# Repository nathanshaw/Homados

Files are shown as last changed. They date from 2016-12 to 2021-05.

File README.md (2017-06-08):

Machine Orchesta
# Homados

16 Channel Solenoid Driver

Please note that for each board you much change the ARDUINO_ID to a unique number

If you want to turn off LED feedback change LED_FEEDBACK to 0

If you don't want the startup sequence change BOOT_TEST to 0

If the LED is not yellow during the BOOT_TEST change your led pins until it is.

-------------------

Homados is the larger of the two actuator shields in the Pantheon system and is 
fashioned for use with the Arduino Mega microcontroller. The board supports 
sixteen channels of actuator control, three I2C jacks, and a RGB status LED. The 
first fifteen channels of the Homados driver utilizes PWM while the sixteenth channel 
uses a standard digital pin. The Homados is intended to function as a larger version of 
the Brigid shield and is to be used when six channels of control are inadequate. The 
Homados shield is functionally comparable to the Brigid in all ways.

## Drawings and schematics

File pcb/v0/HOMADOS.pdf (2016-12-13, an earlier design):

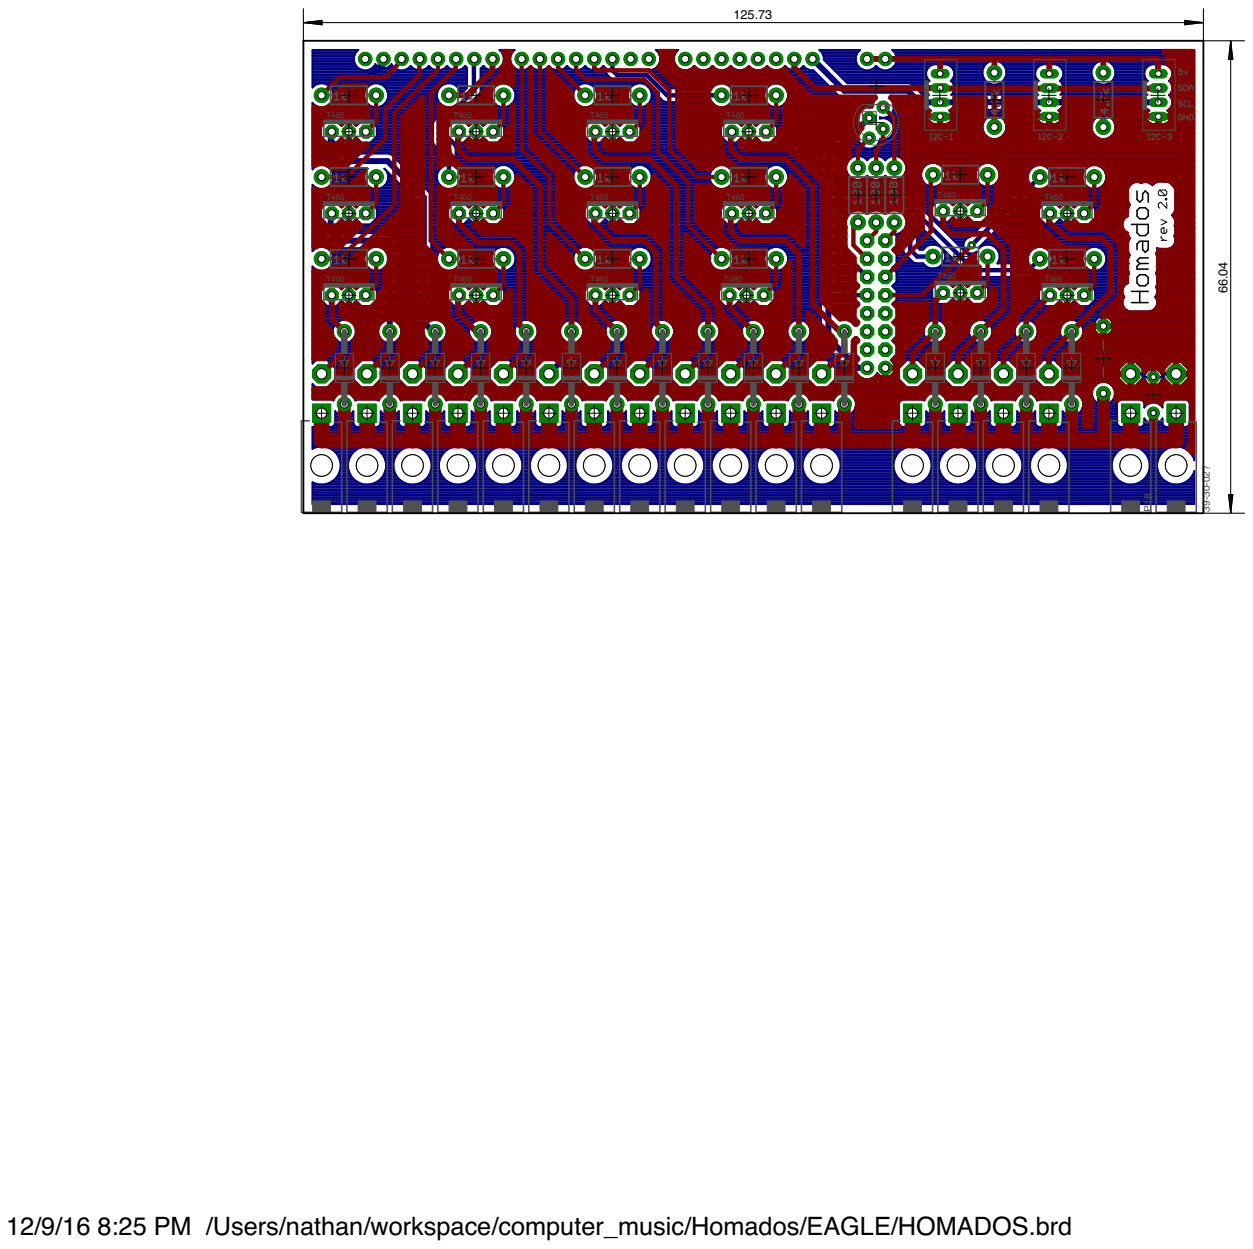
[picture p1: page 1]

12/9/16 8:25 PM /Users/nathan/workspace/computer_music/Homados/EAGLE/HOMADOS.brd

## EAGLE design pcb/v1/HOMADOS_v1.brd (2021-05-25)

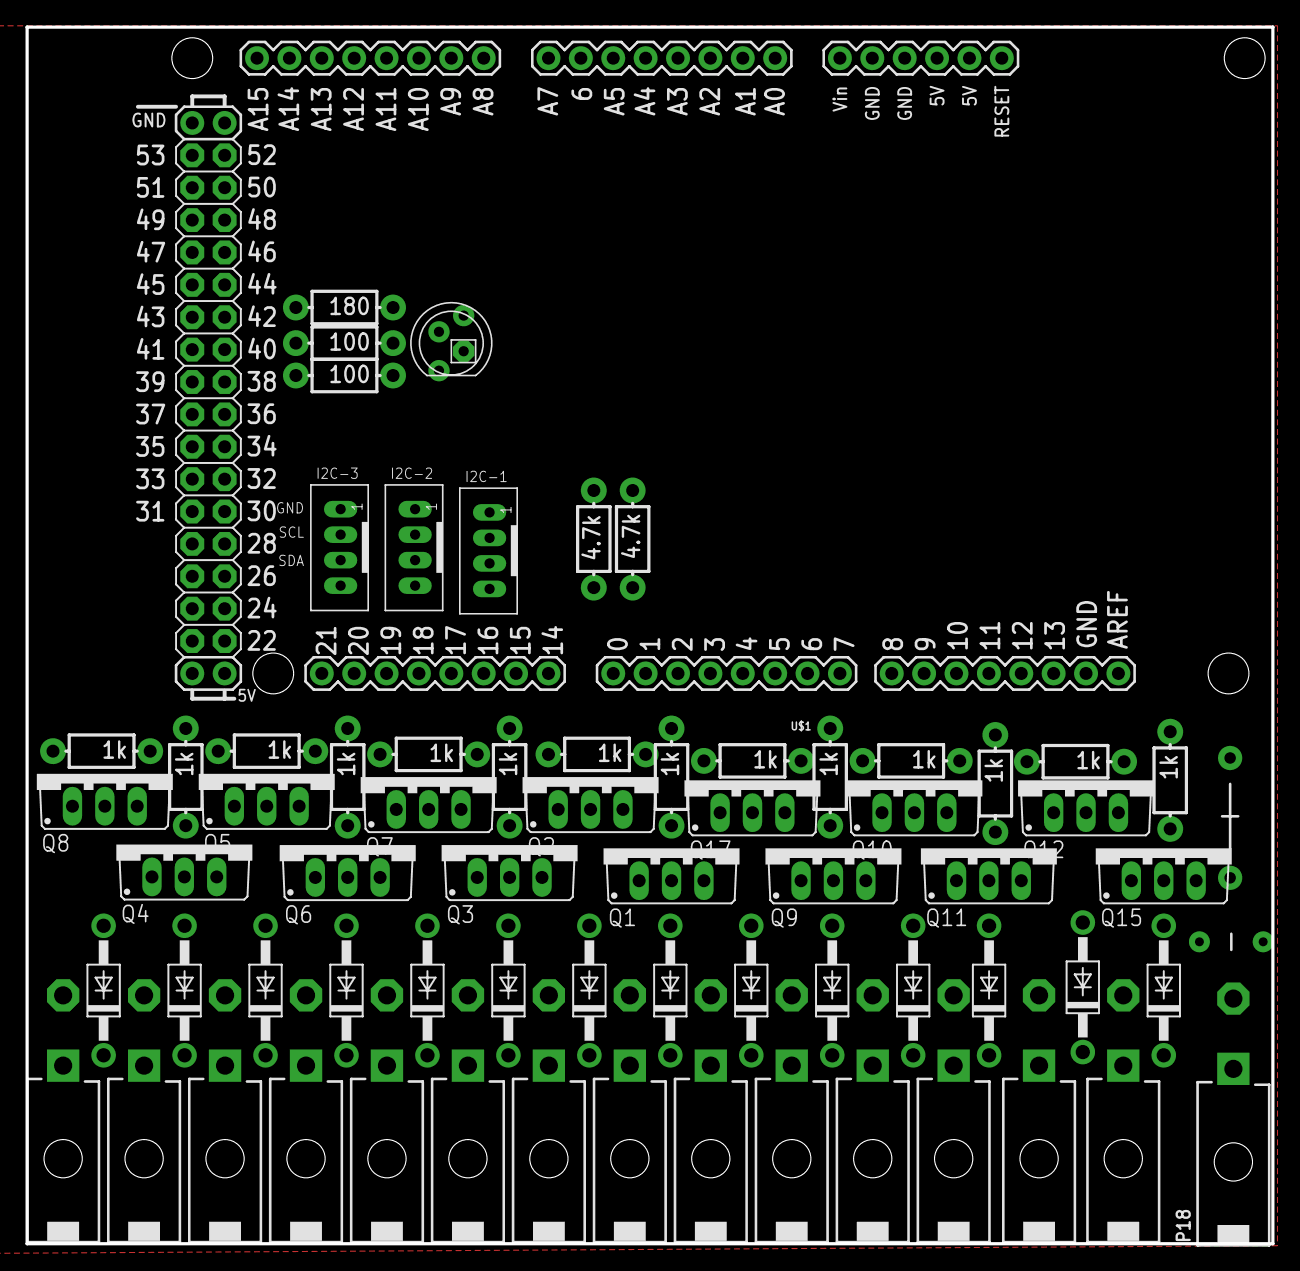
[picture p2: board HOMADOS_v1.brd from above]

Board: 2 copper layers, 97.7 x 95.4 mm, 69 parts (0 on the bottom side), 54 nets, no tracks yet.

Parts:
C1: CAP-PTH-5MM
C2: CAP-PTH-LARGE
D1, D2, D3, D4, D5, D6, D7, D8, D9, D10, D11, D12, D13, D16: 1N4004; DO41-10
I2C-1, I2C-2, I2C-3: JST-PH_4-PIN_HEADER; JST_B4B-PH_HEADER
P1, P3, P4, P5, P6, P7, P8, P9, P10, P11, P12, P13, P14, P17, P18: 39-30-02?; 39-30-?02?
Q1, Q2, Q3, Q4, Q5, Q6, Q7, Q8, Q9, Q10, Q11, Q12, Q15, Q17: TO220BV
R1, R2: 4.7k; AXIAL-0.3-KIT
R3: 180; AXIAL-0.3-KIT
R4, R5, R6, R7, R8, R9, R10, R11, R12, R13, R14, R15, R18, R19: 1k; AXIAL-0.3-KIT
R20, R21: 100; AXIAL-0.3-KIT
U$1: ARDUINO_MEGA
U$2: RGBLED_CA; LED5MMRGB

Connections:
5V: I2C-1.P4, I2C-2.P4, I2C-3.P4, R1.P$2, R2.P$1, U$1.5V@1, U$1.5V@2
A0: R3.P$1, U$2.4
A2: R20.P$1, U$2.1
ARDUINO_GND: U$1.GND@2, U$2.2
BLUE: R3.P$2, U$1.42
D0: R15.P$1, U$1.47
GND: C1.2, C2.2, I2C-1.P1, I2C-2.P1, I2C-3.P1, P18.2, Q1.S, Q2.S, Q3.S, Q4.S, Q5.S, Q6.S, Q7.S, Q8.S, Q9.S, Q10.S, Q11.S, Q12.S, Q15.S, Q17.S, U$1.GND@3, U$1.GND@4
GREEN: R21.P$2, U$1.40
unnamed: R21.P$1, U$2.3
unnamed: D2.A, P3.2, Q17.D
unnamed: D5.A, P6.2, Q7.D
unnamed: D12.A, P13.2, Q11.D
unnamed: Q17.G, R19.P$2
unnamed: Q1.G, R4.P$2
unnamed: D13.A, P14.2, Q15.D
unnamed: Q2.G, R5.P$2
unnamed: D1.A, P1.2, Q1.D
unnamed: D3.A, P4.2, Q2.D
unnamed: Q3.G, R6.P$2
unnamed: D4.A, P5.2, Q3.D
unnamed: D6.A, P7.2, Q6.D
unnamed: D7.A, P8.2, Q5.D
unnamed: Q7.G, R7.P$2
unnamed: D11.A, P12.2, Q10.D
unnamed: Q6.G, R8.P$2
unnamed: D8.A, P9.2, Q4.D
unnamed: Q5.G, R9.P$2
unnamed: D16.A, P17.2, Q12.D
unnamed: D10.A, P11.2, Q9.D
unnamed: Q4.G, R10.P$2
unnamed: D9.A, P10.2, Q8.D
unnamed: Q8.G, R11.P$2
unnamed: Q9.G, R12.P$2
unnamed: Q10.G, R13.P$2
unnamed: Q11.G, R14.P$2
unnamed: Q15.G, R15.P$2
unnamed: Q12.G, R18.P$2
PW0: R14.P$1, U$1.2
PW1: R13.P$1, U$1.3
PW2: R12.P$1, U$1.4
PW3: R19.P$1, U$1.5
PW4: R4.P$1, U$1.6
PW5: R5.P$1, U$1.7
PW6: R6.P$1, U$1.8
PW7: R7.P$1, U$1.9
PW8: R8.P$1, U$1.10
PW9: R11.P$1, U$1.11
PW10: R10.P$1, U$1.12
PW11: R9.P$1, U$1.13
PW12: R18.P$1, U$1.44
PWR: C1.1, C2.1, D1.C, D2.C, D3.C, D4.C, D5.C, D6.C, D7.C, D8.C, D9.C, D10.C, D11.C, D12.C, D13.C, D16.C, P1.1, P3.1, P4.1, P5.1, P6.1, P7.1, P8.1, P9.1, P10.1, P11.1, P12.1, P13.1, P14.1, P17.1, P18.1
RED: R20.P$2, U$1.41
SCL: I2C-1.P2, I2C-2.P2, I2C-3.P2, R2.P$2, U$1.21
SDA: I2C-1.P3, I2C-2.P3, I2C-3.P3, R1.P$1, U$1.20

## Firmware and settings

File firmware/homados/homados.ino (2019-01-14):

/*
  Standard firmware for the Homados 16 channel solinoid driver
  The first 9 channels are PWM driven while the remaining 7 channels are digital

  When loading the firmware onto an Arduino Mega take note of
  the following steps:

  1. if you want the bot to silently boot (not trigger its solinoids)
  set SILENT_BOOT to 1
  2. set LED_FEEDBACK to 1 if you want the LED's to provide runtime feedback
  3. Assign a new ARDUINO_ID: the Homados boards are 11 - 20

*/
#define I2C_S
#include <Wire.h>
#ifdef I2C_S
#define I2C_ID 0x90
#endif

// #define USB_SERIAL
// on H1 10, 12, 14, 16 are broken
#define NUM_SOLENOIDS 16

// botnum/board type/board num
#define PANTHEON
#ifdef PANTHEON
#define BOT_ID 3
#define BOT_TYPE 2
#define ARDUINO_ID 3
#endif

#include <avr/interrupt.h>
#include <avr/io.h>

#define LED_BLUE 42
#define LED_GREEN 40
#define LED_RED 41

#define LED_FEEDBACK 1
#define BOOT_TEST 0

// Function declarations
///////////////////////////////////////
void bootTest();
void pollserial();
void i2cRequest();
void i2cReceive(unsigned int count);

// Global Variables
////////////////////////////////////////
char bytes[2];
short notes[NUM_SOLENOIDS];

int handshake = 0;
int statustimer = 0;

// actuator pins for rev 2
int actuators[] = {
  11, 12, 13, 10,
  9, 44, 7, 6,
  5, 4, 3, 2,
  45, 46, 47, 8
};

///////////// LEDs ///////////////////////////////
char led_pins[] = {LED_RED, LED_GREEN, LED_BLUE};
unsigned long led_last_on[] = {0, 0, 0};
bool led_state[] = {0, 0, 0};

//////////// I2C /////////////////////////////////
#define MEM_LEN 256
char databuf[MEM_LEN];
volatile uint8_t received;

void setup() {
  Serial.begin(57600);

  // interrupt timer parameters, these need to change
  TCCR2A = 1;
  TCCR2B = 3;
  TIMSK2 = 1;

  pinMode(LED_RED, OUTPUT);
  pinMode(LED_GREEN, OUTPUT);
  pinMode(LED_BLUE, OUTPUT);

  // While booting the LED is Yellow
  digitalWrite(LED_RED, HIGH);
  digitalWrite(LED_GREEN, HIGH);
  digitalWrite(LED_BLUE, LOW);
  Serial.println("Running boot tests");
  bootTest();

  // When boot is over the board will give you a green LED if Mode is Serial
#ifdef USB_SERIAL
  digitalWrite(LED_GREEN, HIGH);
  digitalWrite(LED_BLUE, LOW);
  digitalWrite(LED_RED, LOW);
  Serial.println("USB_SERIAL mode is active, the board will expect commands via usb");
#endif

#ifdef I2C_S
  // Wire.begin(I2C_SLAVE, I2C_ID, I2C_PINS_18_19, I2C_PULLUP_EXT, 400000);
  Wire.begin(I2C_ID); // joing i2c bus with address of I2C_ID
  Wire.onReceive(i2cReceive);
  // Wire.onRequest(i2cRequest);
  // data init
  // received = 0;
  // memset(databuf, 0, sizeof(databuf));

  digitalWrite(LED_BLUE, HIGH);
  digitalWrite(LED_GREEN, LOW);
  digitalWrite(LED_RED, LOW);
  Serial.print("I2C mode is active, the board will act as a slave with address");
  Serial.println(I2C_ID);
#endif
  Serial.println("setup loop complete");
  Serial.println("- - - - - - - - - - - -");
}

void loop() {
#ifdef USB_SERIAL
  pollSerial();
#endif
}

void i2cReceive(unsigned int count) {
  // should be the note followed by a velocity
  while (1 < Wire.available()) {
    int n = Wire.read();
    int v = Wire.read();
    statustimer = 60;
    notes[n] = v;
  }
  // Wire.read(databuf, count);
  // received = count;
  // digitalWrite(LED_RED, HIGH);
  // digitalWrite(LED_GREEN, HIGH);
  // digitalWrite(LED_BLUE, HIGH);
  Serial.println("Received I2C Message");
}

void pollSerial() {
  if (Serial.available()) {
    if (Serial.read() == 0xff) {
      // reads in a two index array from ChucK
      Serial.readBytes(bytes, 2);

      // bit wise operations
      // ~~~~~~~~~~~~~~~~~~~
      // reads the first six bits for the note number
      // then reads the last ten bits for the note velocity
      int pitch = byte(bytes[0]) >> 2;
      int velocity = (byte(bytes[0]) << 8 | byte(bytes[1])) & 1023;

      // message required for "handshake" to occur
      // happens once per Arduino at the start of the ChucK serial code
      if (pitch == 63 && velocity == 1023 && handshake == 0) {
        Serial.write(BOT_ID);
        Serial.write(BOT_TYPE);
        Serial.write(ARDUINO_ID);
        handshake = 1;
        digitalWrite(LED_RED, LOW);
        digitalWrite(LED_GREEN, LOW);
      }
      if (pitch >= 0 && pitch <= NUM_SOLENOIDS) {
        statustimer = 120;
        notes[pitch] = (velocity * 0.5);
      }
    }
  }
}

ISR(TIMER2_OVF_vect) {
  // solenoid control
  for (int i = 0; i < NUM_SOLENOIDS; i++) {
    if (notes[i] > 0) {
      digitalWrite(actuators[i], HIGH);
      notes[i]--;
    }
    else {
      digitalWrite(actuators[i], LOW);
    }
  }
  if (statustimer > 0 && LED_FEEDBACK) {
    digitalWrite(LED_BLUE, HIGH);
    statustimer--;
  }
  else {
    digitalWrite(LED_BLUE, LOW);
  }
}

void bootTest() {
  for (int i = 0; i < 12; i++) {
    pinMode(actuators[i], OUTPUT);
    if (BOOT_TEST == 1) {
      notes[i] = 70;
      delay(350);
    }
  }
  delay(1500);
}

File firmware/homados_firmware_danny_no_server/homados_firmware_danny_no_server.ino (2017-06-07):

/*
    Standard firmware for the Homados 16 channel solinoid driver
 The first 9 channels are PWM driven while the remaining 7 channels are digital
 
 When loading the firmware onto an Arduino Mega take note of
 the following steps:
 
 1. if you want the bot to silently boot (not trigger its solinoids) 
 set SILENT_BOOT to 1
 2. set LED_FEEDBACK to 1 if you want the LED's to provide runtime feedback
 3. Assign a new ARDUINO_ID: the Homados boards are 11 - 20
 
 */
// on H1 10, 12, 14, 16 are broken
# define NUM_SOLENOIDS 16

#include <avr/interrupt.h>
#include <avr/io.h>

#define LED_RED 41
#define LED_GREEN 40
#define LED_BLUE 42

#define LED_FEEDBACK 1
#define BOOT_TEST 1

char bytes[2];
short notes[NUM_SOLENOIDS];

int handshake = 0;
int statustimer = 0;

// min amount of ms between actuator triggers
int cooldown = 500;
//actuator pins v2
int actuators[] = {
  11, 12, 13, 10, 9, 8, 7, 6, 5, 4, 3, 2,
  44, 45, 46, 47
};

int last_triggered[NUM_SOLENOIDS];

void setup() {
  // interrupt timer parameters, these need to change
  TCCR2A = 1;
  TCCR2B = 3;
  TIMSK2 = 1;

  pinMode(LED_RED, OUTPUT);
  pinMode(LED_GREEN, OUTPUT);
  pinMode(LED_BLUE, OUTPUT);
  digitalWrite(LED_RED, HIGH);
  for (int i = 0; i < NUM_SOLENOIDS; i++) {
    pinMode(actuators[i], OUTPUT);
    if (BOOT_TEST == 1){
      notes[i] = 100;
      delay(100);  
    }
  }
  delay(1000);
  digitalWrite(LED_RED, LOW);
}

ISR(TIMER2_OVF_vect) {
  // solenoid control
  for (int i = 0; i < NUM_SOLENOIDS; i++) {
    if (notes[i] > 0) {
      digitalWrite(actuators[i], HIGH);
      notes[i]--;
    }
    else {
      digitalWrite(actuators[i], LOW);
    }
  }
  if (statustimer > 0 && LED_FEEDBACK) {
    digitalWrite(LED_BLUE, HIGH);
    statustimer--;
  }
  else {
    digitalWrite(LED_BLUE, LOW);
  }
}


void loop() {
  statustimer = 120;
  for (int i = 0; i < NUM_SOLENOIDS; i++){
    // this will activate the actuator 5% of the time
    // but allows for multiple ones to be activated at once
    if (random(0, 100) < 5){
      // what you make notes[i] equal to
      // corresponds to velocity, or time on 
      // where i is the number of actuator you 
      // are addressing

      // if an amount of ms greater than cooldown has passed
      // from the last time the actuator was triggered...
      // activate it again
      if (last_triggered[i] + cooldown < millis()){
        notes[i] = 100;
        // this allows you to keep track of the last time 
        // the actuator was triggered
        last_triggered[i] = millis();
      }
    }
  }
}

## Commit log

2016-12-13 created v2 of Homados board
    [HOMADOS.brd, HOMADOS.sch]
2017-02-01 touch up on v2 board
    [HOMADOS.brd]
2017-02-06 moved some things around
    [HOMADOS.brd, HOMADOS.sch]
2017-02-17 finished revision of homados
    [HOMADOS.brd, HOMADOS.sch]
2017-03-16 updated Homados board and firmware
    [HOMADOS.brd]
2017-06-07 added some specialized firmware
    [HOMADOS.brd, HOMADOS.sch]
2021-05-25 Started to update the EAGLE design for production
    [HOMADOS.brd, HOMADOS.sch, HOMADOS_v1.brd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]

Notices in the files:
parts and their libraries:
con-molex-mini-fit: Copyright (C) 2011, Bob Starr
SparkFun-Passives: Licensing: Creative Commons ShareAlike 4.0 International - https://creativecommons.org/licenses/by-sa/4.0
